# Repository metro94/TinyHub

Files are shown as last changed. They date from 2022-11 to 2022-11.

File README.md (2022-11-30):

# TinyHub - 4-Port USB Hub with Multi-TT

## Introduction

A tiny USB hub with support of Multi-TT (Transaction Translator), powered by CH334R.

## 3D Rendering View

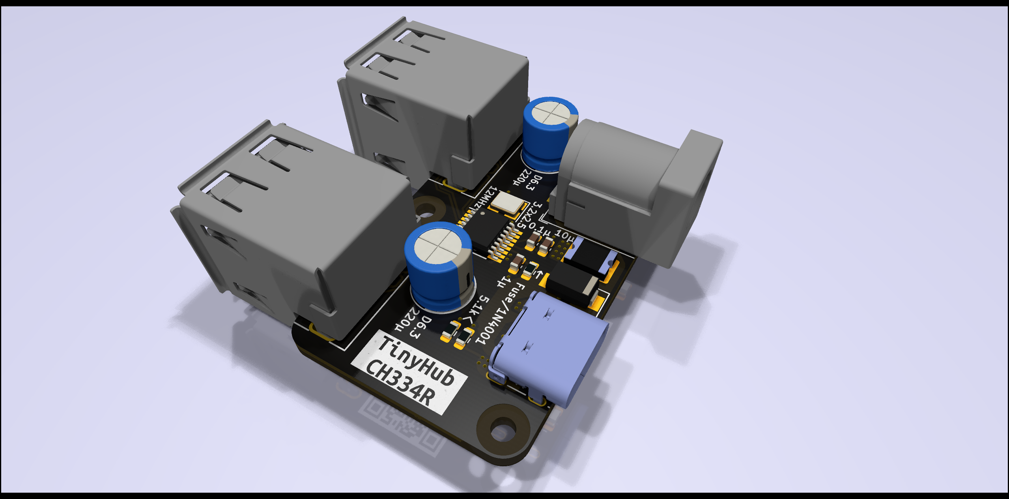
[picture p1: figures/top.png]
Top View


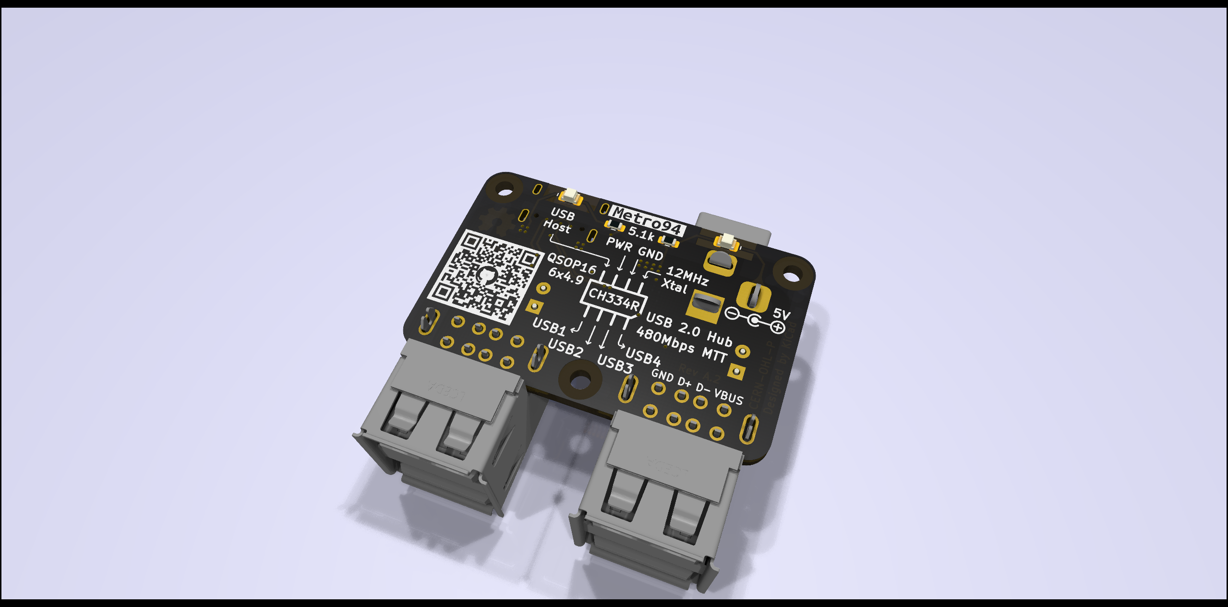
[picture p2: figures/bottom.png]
Bottom View


## License

[CERN-OHL-P](LICENSE)

## EDA

KiCad 6.0.6

## Usages

This PCB can be used with CH334R.

`Fuse/1N4004` selection is depended on CH334 version:

* For the first version of CH334 with 0 in the penultimate 5 digits of the lot number, this device is changed to 1N4001 or similar diode.
* Otherwise, this device should be a 100mA fuse resistor, or for simplified applications, 0Ω can be used.

NOTE: For the first version of CH334R, it could be lack of Multi-TT support, and tools such as USBTreeView would report that hub is Single-TT. For my test, CH334R with the lot number `31160HC16` is **NOT** Multi-TT supported, and `31161HC43` is. I suggest to contact Qinheng for more information.

### Schematics

[TinyHub Schematic](schematics/TinyHub.pdf)

### BOM

[TinyHub BOM](https://metro94.github.io/TinyHub/bom.html)

### Product Page

[USB HUB Controller – CH334/5 - NanjingQinhengMicroelectronics](http://www.wch-ic.com/products/CH334.html)

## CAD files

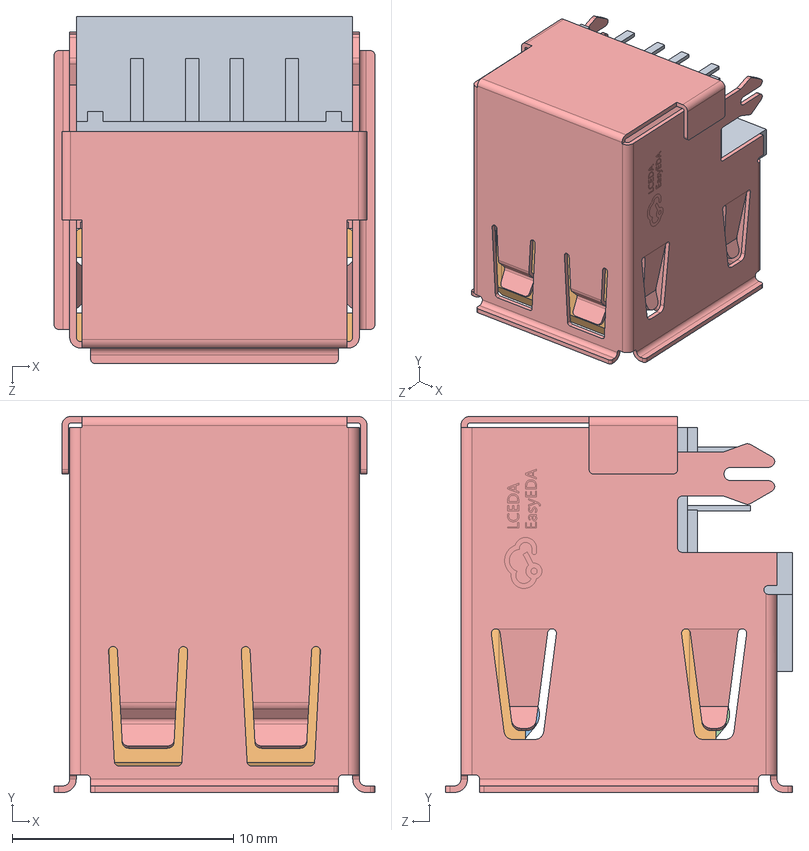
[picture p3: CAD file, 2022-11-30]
USB-A-TH_907-421A1016P10200.step
14.5 x 17.0 x 15.7 mm

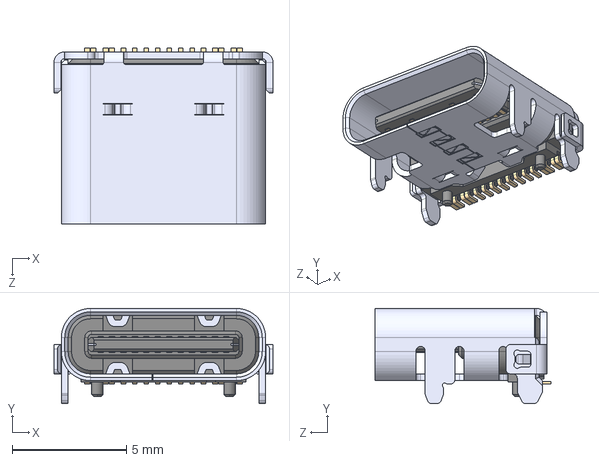
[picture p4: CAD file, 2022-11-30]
USB4105_GF_A.STEP
9.58 x 4.16 x 7.71 mm

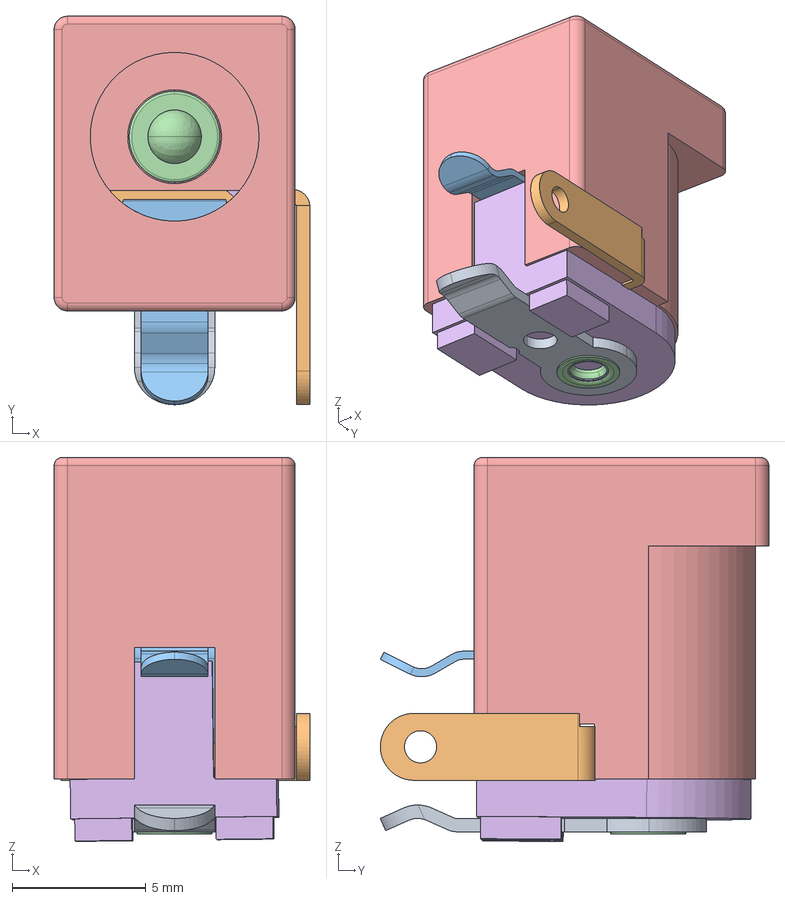
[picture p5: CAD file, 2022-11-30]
BarrelJack.stp
9.55 x 14.5 x 14.3 mm

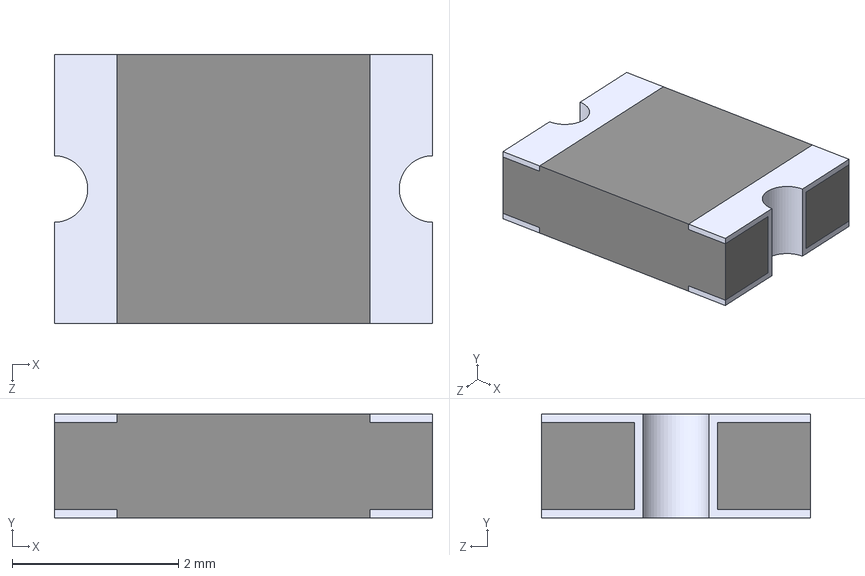
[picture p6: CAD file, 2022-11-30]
Fuse_1812.STEP
4.55 x 1.25 x 3.24 mm

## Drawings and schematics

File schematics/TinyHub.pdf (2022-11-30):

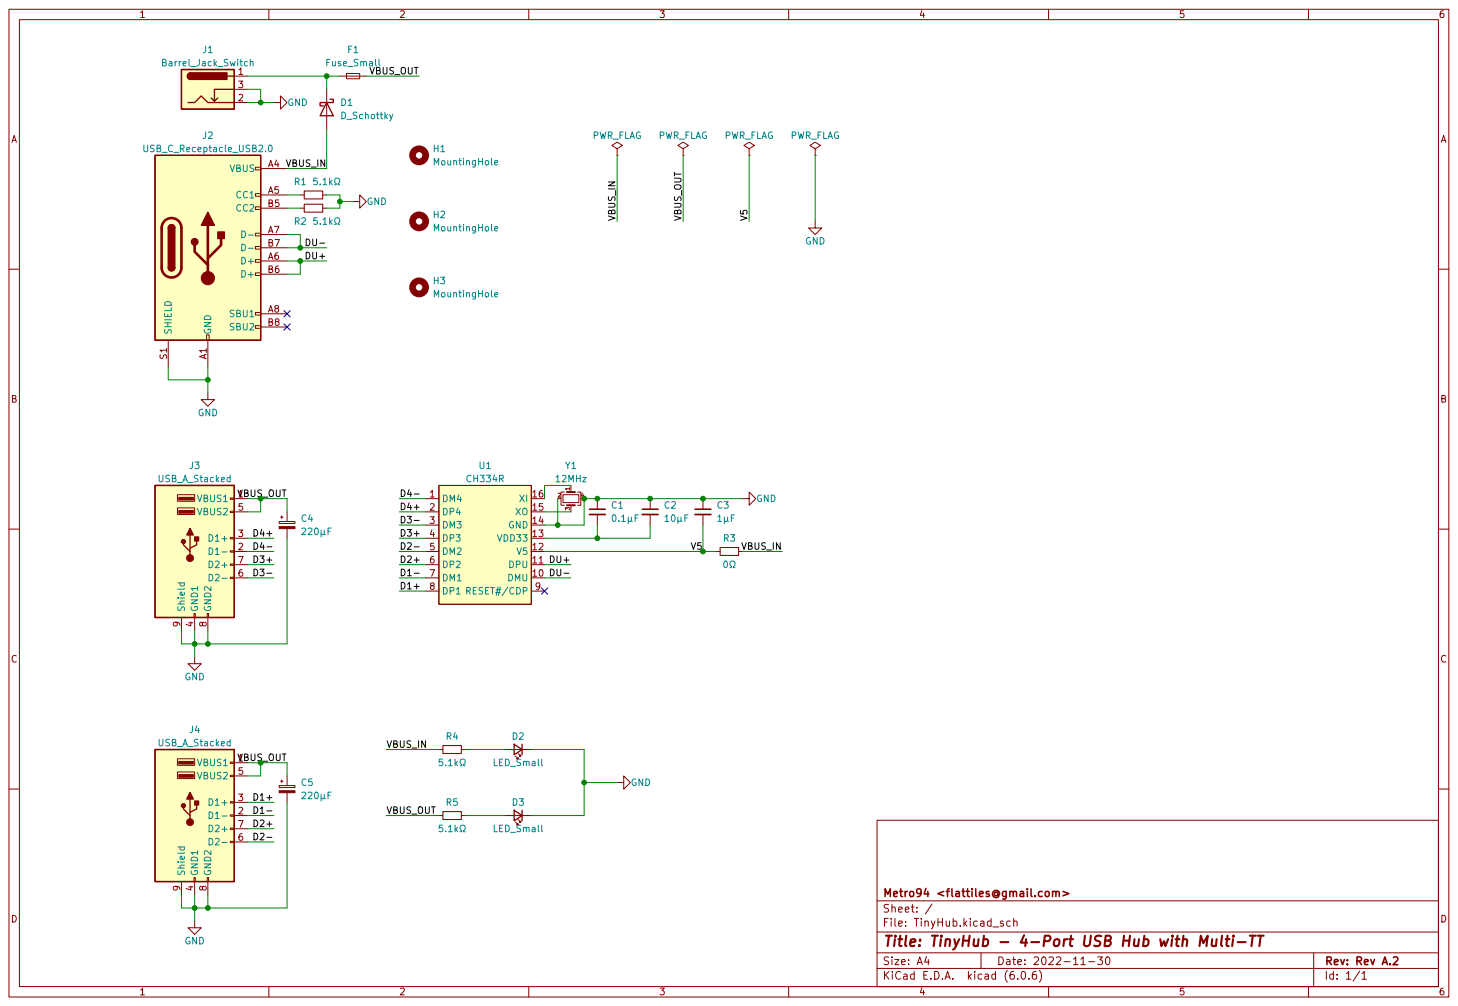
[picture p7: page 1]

File: TinyHub.kicad_sch Sheet: / Metro94 <flattiles@gmail.com>

Id: 1/1 Title: TinyHub - 4-Port USB Hub with Multi-TT

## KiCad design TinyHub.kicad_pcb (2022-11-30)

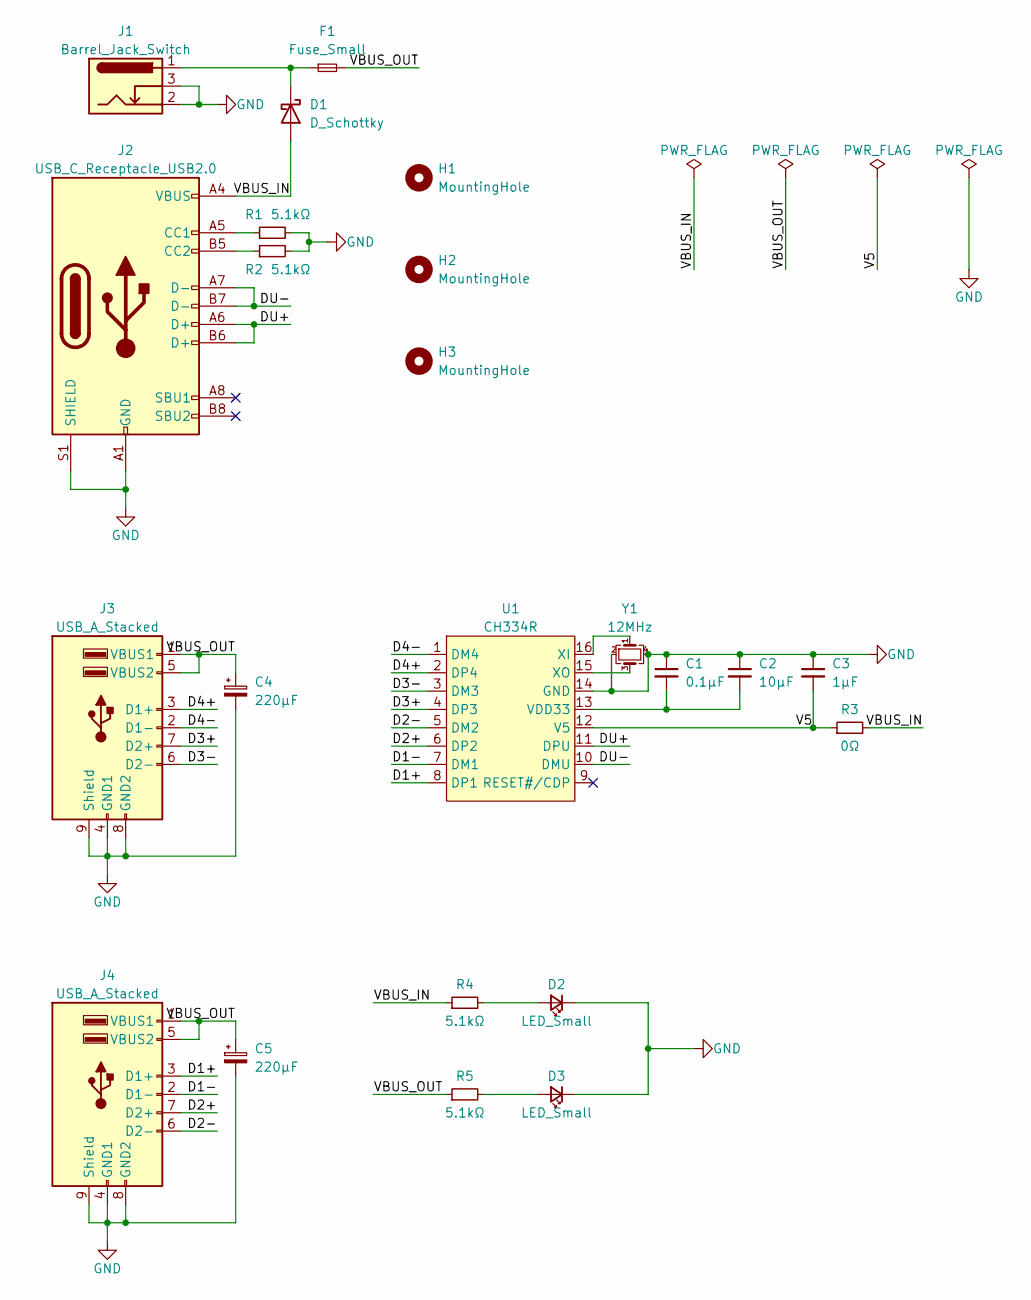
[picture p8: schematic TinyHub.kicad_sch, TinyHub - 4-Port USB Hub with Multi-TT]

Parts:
C1: 0.1μF; C_0603_1608Metric
C2: 10μF; C_0603_1608Metric
C3: 1μF; C_0603_1608Metric
C4, C5: 220μF; CP_Radial_D6.3mm_P2.50mm
D1: D_Schottky; D_SMA
D2, D3: LED_Small; LED_0805_2012Metric
F1: Fuse_Small; Fuse_1812_4532Metric
H1, H2, H3: MountingHole; MountingHole_2.2mm_M2
J1: Barrel_Jack_Switch; BarrelJack_Horizontal
J2: USB_C_Receptacle_USB2.0; USB_C_Receptacle_Palconn_UTC16-G
J3, J4: USB_A_Stacked; USB_Offset_Stacked
R1, R2, R4, R5: 5.1kΩ; R_0603_1608Metric
R3: 0Ω; R_0603_1608Metric
U1: CH334R; QSOP-16_3.9x4.9mm_P0.635mm
Y1: 12MHz; Crystal_SMD_3225-4Pin_3.2x2.5mm

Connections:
/D1+: J4.3 (D1+), U1.8 (DP1)
/D1-: J4.2 (D1-), U1.7 (DM1)
/D2+: J4.7 (D2+), U1.6 (DP2)
/D2-: J4.6 (D2-), U1.5 (DM2)
/D3+: J3.7 (D2+), U1.4 (DP3)
/D3-: J3.6 (D2-), U1.3 (DM3)
/D4+: J3.3 (D1+), U1.2 (DP4)
/D4-: J3.2 (D1-), U1.1 (DM4)
/DU+: J2.A6 (D+), J2.B6 (D+), U1.11 (DPU)
/DU-: J2.A7 (D-), J2.B7 (D-), U1.10 (DMU)
/V5: C3.2, R3.1, U1.12 (V5)
/VBUS_IN: D1.2 (A), J2.A4 (VBUS), J2.A9 (VBUS), J2.B4 (VBUS), J2.B9 (VBUS), R3.2, R4.1
/VBUS_OUT: C4.1, C5.1, F1.2, J3.1 (VBUS1), J3.5 (VBUS2), J4.1 (VBUS1), J4.5 (VBUS2), R5.1
GND: C1.1, C2.1, C3.1, C4.2, C5.2, D2.1 (K), D3.1 (K), J1.2, J1.3, J2.A1 (GND), J2.A12 (GND), J2.B1 (GND), J2.B12 (GND), J2.S1 (SHIELD), J3.4 (GND1), J3.8 (GND2), J3.9 (Shield), J4.4 (GND1), J4.8 (GND2), J4.9 (Shield), R1.2, R2.2, U1.14 (GND), Y1.2, Y1.4
unnamed: C1.2, C2.2, U1.13 (VDD33)
unnamed: D1.1 (K), F1.1, J1.1
unnamed: D2.2 (A), R4.2
unnamed: D3.2 (A), R5.2
unnamed: J2.A5 (CC1), R1.1
unnamed: J2.B5 (CC2), R2.1
unnamed: U1.15 (XO), Y1.3
unnamed: U1.16 (XI), Y1.1

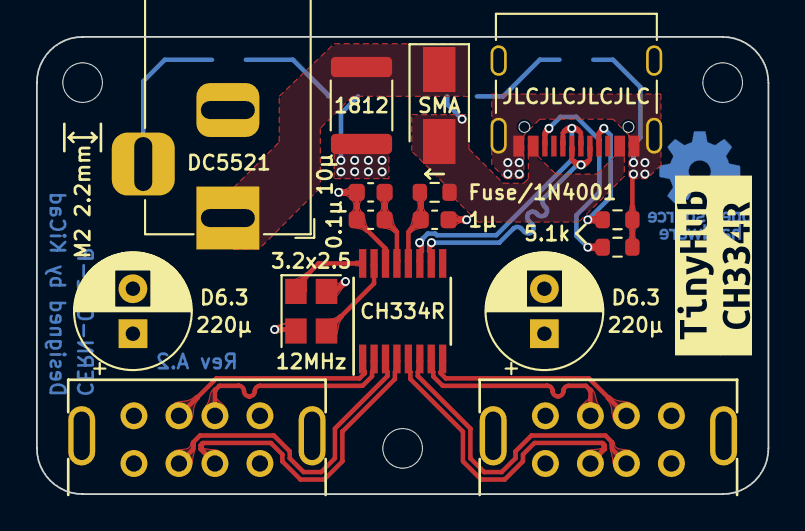
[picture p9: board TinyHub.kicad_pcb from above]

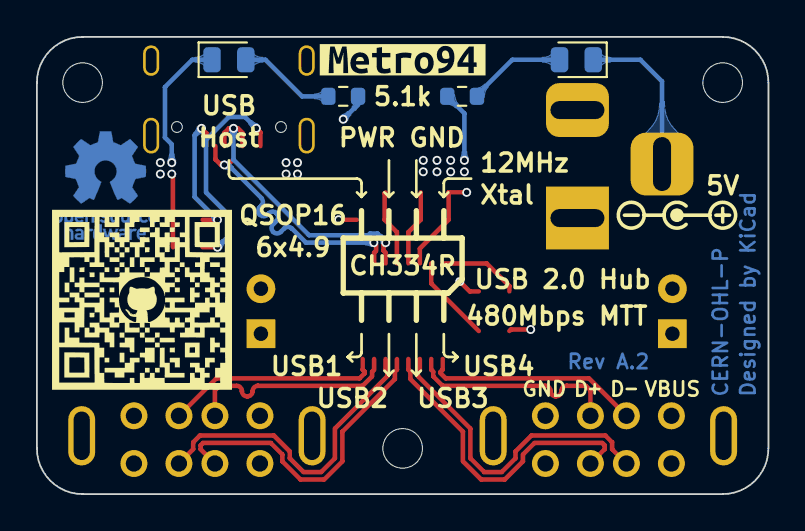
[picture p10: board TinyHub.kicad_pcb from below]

Board: 4 copper layers, 40.6 x 25.4 mm, 26 parts (5 on the bottom side), 22 nets.

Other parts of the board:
kibuzzard-635414B2: G***; kibuzzard-635414B2
kibuzzard-635414BB: G***; kibuzzard-635414BB
kibuzzard-63727825: G***; kibuzzard-63727825
